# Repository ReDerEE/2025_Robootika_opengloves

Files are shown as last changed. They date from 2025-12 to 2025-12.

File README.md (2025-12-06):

# Robootika iseseisev arendusprojekt

See repositoorium on mõeldud IFI6203.DT kursuse "Robootika" üliõpilastele.  
Iga meeskond **forkib** selle repo ja dokumenteerib siin oma seadme/projekti:
- *mis probleemi lahendate ja miks see seade kasulik on;*
- *millest seade koosneb (riistvara, kood, 3D prinditud detailid jne);*
- *kuidas seade töötab;*
- *kuidas seda uuesti ehitada.*

## Kuidas seda repo't kasutada

1. Vajuta ülal paremas nurgas **Fork**.
2. Muuda `docs/PROJEKTIDOKUMENTATSIOON.md` enda projekti järgi.
3. Pane kogu kood kataloogi `src/`.
4. Pane skeemid ja riistvara info kataloogi `hardware/`.
5. Lisa pildid / videod kataloogi `media/`.
6. Commiti regulaarselt (isegi pooleliolevad sammud on okei – oluline on arengulugu).

## Projekti minimaalne sisu hindamiseks

- Täidetud dokumentatsioon failis `docs/PROJEKTIDOKUMENTATSIOON.md`
- Töötav kood failis/failides `src/`
- Ühendusskeem (foto / joonis / Fritzing eksport `hardware/wiring-diagram.png`)
- Komponentide loetelu koos linkidega `hardware/komponentide-loetelu.md`

## Meeskond

- Õppeaine: IFI6203.DT Robootika  
- Autor(id): Carl-Eric Sepp, Henri Rihard Pallas
- Aasta / semester: 2025 Sügis

> NB! Ärge kustutage osi, mis on nõutud, küll aga võite lisada lisafaile (katsetused, logid, alternatiivsed skeemid jne).

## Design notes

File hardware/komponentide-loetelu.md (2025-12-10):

# Komponentide loetelu

## Põhikomponendid
**Komponendid ühe (1) kinda kohta, mõlema käe jaoks kahekordistada.**
- _(1x) ESP32-WROOM-32U WROVER_
- _(1x) Xiaomi Redmi Power Bank (20000mAh)_
- _(5x) MG90S Micro Servo Motor (180)_
- _(1x) Joystick, Joystick for Arduino Dual-axis_
- _(5x) Rotary Potentiometer (6mm, 3 pin, 10K ohm)
- _(Optional) Momentary Push Button Switch_  
- _(5x) Vedru (Vaadake lingid/allikad alla)_
- _(5x) Nööri (Vaadake lingid/allikad alla)_
- _Kaablid_
- _Kaablite otsad_

3D Prinditud:
- _End caps (hardware/3D/EndCaps.stl)_
- _Guide Nodes (hardware/3D/GuideNode.STL)_
- _Guide Rings (hardware/3D/guideRings.stl)_
- _Haptic Spool (hardware/3D/HapticSpool.stl)_
- _Left hand mount (hardware/3D/LeftHandMount.STL)_
- _Potentiometer holder (hardware/3D/PotHolder.STL)_
- _Quest2 holder (hardware/3D/Quest2Holder.stl)
- _Right hand mount (hardware/3D/RightHandMount.STL)_
- _Spool cover (hardware/3D/Spoolcover.stl)_
- _Tensioner (hardware/3D/Tensioner.stl)_

## Lingid / allikad
- ESP32-WROOM-32U WROVER – [Aliexpress](https://www.aliexpress.com/item/1005008209898668.html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)
- Xiaomi Redmi Power Bank 20000mAh – [Arvutitark](https://arvutitark.ee/en/smart-devices/smart-device-accessories/akupangad/xiaomi-redmi-fast-charge-power-bank-20000-mah-black-18-w-1017875)
- MG90S Micro Servo Motor – [Aliexpress](https://www.aliexpress.com/item/1005005672961991.html?spm=a2g0o.order_list.order_list_main.20.30fa1802Zp5XaK)
- Joystick for Arduino Dual-axis - [Aliexpress](https://www.aliexpress.com/item/1005007915984781.html?spm=a2g0o.order_list.order_list_main.30.30fa1802Zp5XaK)
- Nupud - [Aliexpress_ET](https://www.aliexpress.com/item/4001081730289.html?spm=a2g0o.order_list.order_list_main.40.30fa1802Zp5XaK) [Aliexpress_EN](https://www.aliexpress.us/item/2255800895415537.html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)
- Potentsiomeetrid - [Aliexpress](https://www.aliexpress.com/item/33011428749.html?spm=a2g0o.order_list.order_list_main.25.30fa1802Zp5XaK)
- Kaablid - [Aliexpress](https://www.aliexpress.com/item/1005007156114505.html?spm=a2g0o.order_list.order_list_main.50.30fa1802Zp5XaK)
- Kaablite otsad [Aliexpress](https://www.aliexpress.com/item/1005007425641197.html?spm=a2g0o.order_list.order_list_main.15.30fa1802Zp5XaK)
- Nöörid ja vedrud saadud antud toote lahti võtmisel [Aliexpress](https://www.aliexpress.us/item/3256803821144861.html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)

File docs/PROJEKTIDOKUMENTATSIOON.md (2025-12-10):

# Projekti dokumentatsioon

## 1. Projekti eesmärk ja seadme lühikirjeldus
**Mis asi see on, mida ja miks me teeme? Millist praktilist probleemi see lahendab?**

- Meie projekti eesmärk on luua haptilised kindad, mida saab kasutada virtuaal reaalsues (VR), virutaalsete objektide tunnetamiseks.
- Seade annab võimaluse oma enda kätega tunnetada virtuaalseid objekte, aitab kaasa virtuaal reaalsuse immersiooniga.
- Peamised komponendid: ESP32 mikrokontroller, akupangad, servomootorid, joystick, potentsiomeetrid, nupp, vedrud, nöörid, 3d prinditud osad kinnitamiseks ja kandmiseks. 

---

## 2. Sisendite loetelu
**Millised on süsteemi poolt loetavad / mõõdetavad sisendid? Millega neid mõõdetakse / tuvastatakse?**

- Potentsiomeetrid:
  - Väikesõrme painutus -> analoogpinge loetakse ESP32 pinilt **PIN_PINKY (36)**
  - Nimetissõrme painutus -> analoogpinge ESP32 pinilt **PIN_RING (39)**
  - Keskmise sõrme painutus -> analoogpinge ESP32 pinilt **PIN_MIDDLE (34)**
  - Nimetissõrme painutus -> analoogpinge ESP32 pinilt **PIN_INDEX (35)**
  - Pöidla painutus -> analoogpinge ESP32 pinilt **PIN_THUMB (32)**

- Joystick
  - Joystick X-telg -> analoogpinge ESP32 pinilt **PIN_JOY_X (12)**
  - Joystick Y-telg -> analoogpinge ESP32 pinilt **PIN_JOY_Y (14)**
  - Joystick vajutusnupp -> digitaalne sisend ESP32 pinilt **PIN_JOY_BTN (26)**

- Bluetooth sisend -> Saab kätte mootorite kontrollimiseks vajaliku informatsiooni.
---

## 3. Väljundite loetelu
**Mida süsteem teeb / muudab? Millega väljund realiseeritakse?**

- Sõrmede jõutagasiside (force feedback):
  Osutavad vastupanu, kui kasutaja puudutab midagi virtuaal reaalsuses.
  - Väikesõrme servo/mootor -> **PIN_PINKY_MOTOR (5)**
  - Nimetissõrme servo/mootor -> **PIN_RING_MOTOR (18)**
  - Keskmise servo/mootor -> **PIN_MIDDLE_MOTOR (19)**
  - Nimetissõrme servo/mootor -> **PIN_INDEX_MOTOR (16)**
  - Pöidla servo/mootor -> **PIN_THUMB_MOTOR (17)**

- Debug LED -> **LED (PIN 2)**

- Bluetooth väljund -> Saadab sõrmede asendid, Žestide olekud, Joysticki asendi.

---

## 4. Nõuded loodavale seadmele
**Mis peab toimuma, kui kasutaja teeb mingi toimingu? Kirjelda käitumisloogika.**

- Kui näpp liigutatakse, siis see saadab näppude painduvuse edasi, siis driver tõlgendab seda Valve Knuckles grip väärtuseks.
- Kui kasutaja liigutab käe interactible objekti lähedusse, siis see paneb servod käima, et kasutaja ei saaks objekti mõistes näppe sellest läbi pista(force feedback osa)
- Kui kasutaja liigutab joystick'i, siis see saadetakse driver'ile ja see tõlgib seda reaalsel kasutatavaks vr joystick'i liigutuseks 

---

## 5. Süsteemi füüsiliste komponentide loetelu
**Millest seade koosneb? Lisa lingid või täpsed nimed, et keegi teine saaks sama asja uuesti osta / teha.**

Tabelina või punktidena. Nt:

- _(1x) ESP32-WROOM-32U WROVER_ [Aliexpress](https://www.aliexpress.com/item/1005008209898668.html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)
- _(2x) Xiaomi Redmi Power Bank (20000mAh)_ [Arvutitark](https://arvutitark.ee/en/smart-devices/smart-device-accessories/akupangad/xiaomi-redmi-fast-charge-power-bank-20000-mah-black-18-w-1017875)
- _(5x) MG90S Micro Servo Motor (180)_ [Aliexpress](https://www.aliexpress.com/item/1005005672961991.html?spm=a2g0o.order_list.order_list_main.20.30fa1802Zp5XaK)
- _(1x) Joystick, Joystick for Arduino Dual-axis_ [Aliexpress](https://www.aliexpress.com/item/1005007915984781.html?spm=a2g0o.order_list.order_list_main.30.30fa1802Zp5XaK)
- _(5x) Rotary Potentiometer (6mm, 3 pin, 10K ohm) [Aliexpress](https://www.aliexpress.com/item/33011428749.html?spm=a2g0o.order_list.order_list_main.25.30fa1802Zp5XaK)
- _(Optional) Momentary Push Button Switch_  [Aliexpress_ET](https://www.aliexpress.com/item/4001081730289.html?spm=a2g0o.order_list.order_list_main.40.30fa1802Zp5XaK) [Aliexpress_EN](https://www.aliexpress.us/item/2255800895415537.html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)
- _(5x) Vedru ja (5x) Nööri (Saadud lingitud toote lahti lammutamisel.)_ [Aliexpress](https://www.aliexpress.us/item/3256803821144861.html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)
- _Kaablid_ [Aliexpress](https://www.aliexpress.com/item/1005007156114505.html?spm=a2g0o.order_list.order_list_main.50.30fa1802Zp5XaK)
- _Kaablite otsad_ [Aliexpress](https://www.aliexpress.com/item/1005007425641197.html?spm=a2g0o.order_list.order_list_main.15.30fa1802Zp5XaK)
- _3D prinditud osad_ (hardware/3D kaustas)

---

## 6. Ühendusskeem
**Kuidas kõik osad on omavahel ühendatud?**
[hardware/wiring-diagram.png]

- Väikesõrme Potentsiomeeteri asend -> **PIN_PINKY (36)**
- Nimetissõrme Potentsiomeeteri asend -> **PIN_RING (39)**
- Keskmise sõrme Potentsiomeeteri asend -> **PIN_MIDDLE (34)**
- Nimetissõrme Potentsiomeeteri asend -> **PIN_INDEX (35)**
- Pöidla Potentsiomeeteri asend -> **PIN_THUMB (32)**

- Joystick X-telg asend -> **PIN_JOY_X (12)**
- Joystick Y-telg asend -> **PIN_JOY_Y (14)**
- Joystick nupu vajutus -> **PIN_JOY_BTN (26)**

- Väikesõrme servo/mootor -> **PIN_PINKY_MOTOR (5)**
- Nimetissõrme servo/mootor -> **PIN_RING_MOTOR (18)**
- Keskmise servo/mootor -> **PIN_MIDDLE_MOTOR (19)**
- Nimetissõrme servo/mootor -> **PIN_INDEX_MOTOR (16)**
- Pöidla servo/mootor -> **PIN_THUMB_MOTOR (17)**

- Väikesõrme Potentsiomeeter ground -> **PIN(GROUND)**
- Nimetissõrme Potentsiomeeter ground -> **PIN(GROUND)**
- Keskmise sõrme Potentsiomeeter ground -> **PIN(GROUND)**
- Nimetissõrme Potentsiomeeter ground -> **PIN(GROUND)**
- Pöidla Potentsiomeeter ground -> **PIN(GROUND)**
- Väikesõrme servo/mootor ground -> **PIN(GROUND)**
- Nimetissõrme servo/mootor ground -> **PIN(GROUND)**
- Keskmise servo/mootor ground -> **PIN(GROUND)**
- Nimetissõrme servo/mootor ground -> **PIN(GROUND)**
- Pöidla servo/mootor ground -> **PIN(GROUND)**
- Joystick ground -> **PIN(GROUND)**
- Nupp ground -> **PIN(GROUND)**
- Vooluallika ground -> **PIN(GROUND)**

- Vooluallikas 1 -> **PIN(5V/Voltage In)** või **USB-C Input**
- Vooluallikas 2 -> Kõik servomootorid

- **PIN(3.3V)** -> Väikesõrme Potentsiomeeteri vool
- **PIN(3.3V)** -> Nimetissõrme Potentsiomeeteri vool
- **PIN(3.3V)** -> Keskmise sõrme Potentsiomeeteri vool
- **PIN(3.3V)** -> Nimetissõrme Potentsiomeeteri vool
- **PIN(3.3V)** -> Pöidla Potentsiomeeteri vool
- **PIN(3.3V)** -> Joystick vool

---

## 7. Süsteemi juhtiv kood (või pseudokood)
**Kirjelda programmi loogikat nii, et seda on võimalik aru saada ka hiljem.**  
[src/lucidgloves-main]  

Kontroller loeb potentsiomeetrite ja joystick-i olekut ning saab läbi bluetoothi informatsiooni driverilt.
Kontroller käivitab servod, kui kasutaja puudutab virtuaalses reaalsuses objekti.
Servod hoiavad käe ja sõrmed paigal, ei lase neil virtuaalse objekti sisse vajuda.
Kontroller saadab driverile potentsiomeetrite ja joystick-i seisundid (nupud ka, kui on).

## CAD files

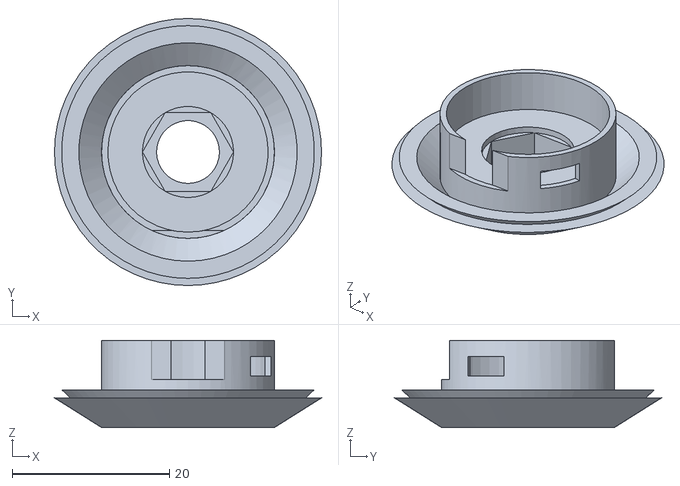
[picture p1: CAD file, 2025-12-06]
hardware/3D/Tensioner.stl
34.0 x 34.0 x 11.1

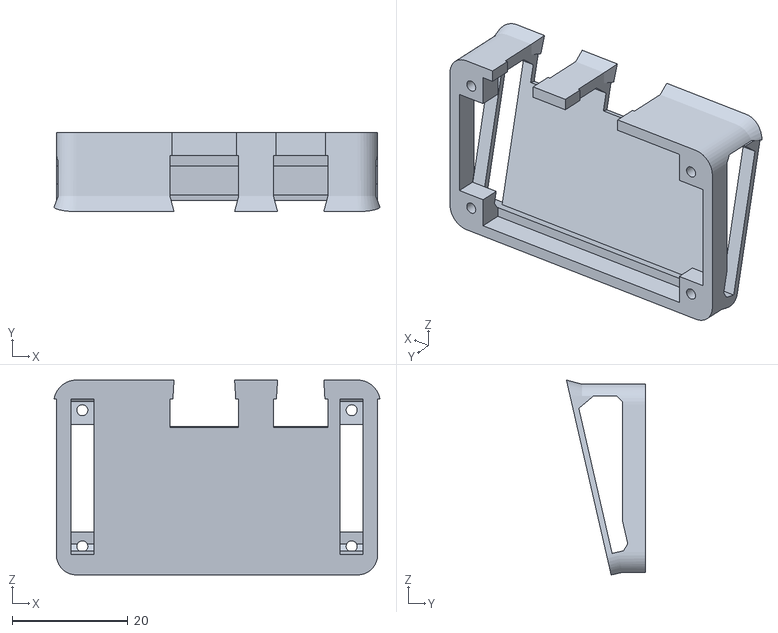
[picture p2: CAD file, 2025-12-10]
src/lucidgloves-main/lucidgloves-main/hardware/MicrocontrollerMounts/ESP32_Wroom_Holder_Desoldered_JST.STL
56.3 x 13.7 x 33.7

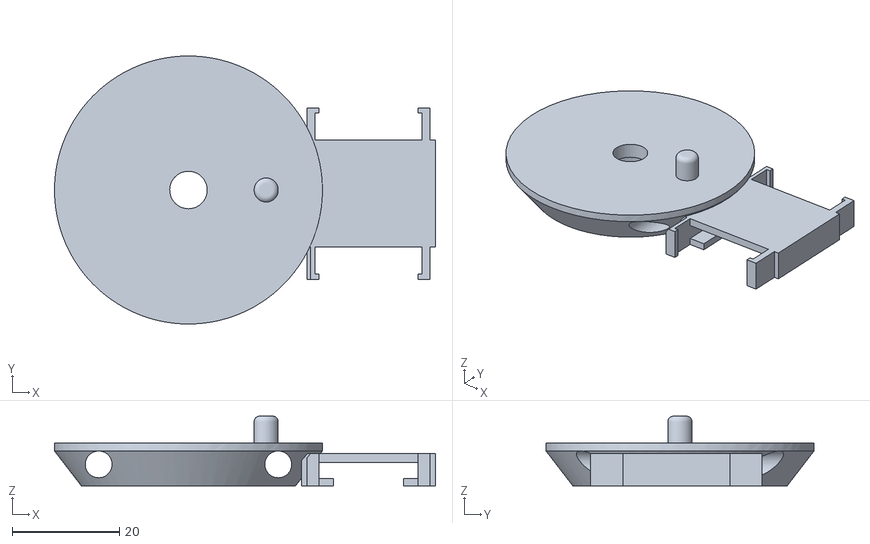
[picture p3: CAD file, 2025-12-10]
src/lucidgloves-main/lucidgloves-main/hardware/Prototype4.1/Vive3.0_MountSlider_v1.2.STL
71.1 x 50.0 x 13.0

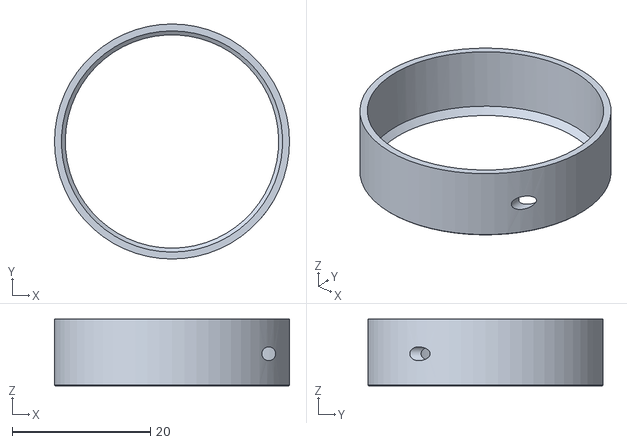
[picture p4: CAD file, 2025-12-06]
hardware/3D/Spoolcover.stl
34.0 x 34.0 x 9.63

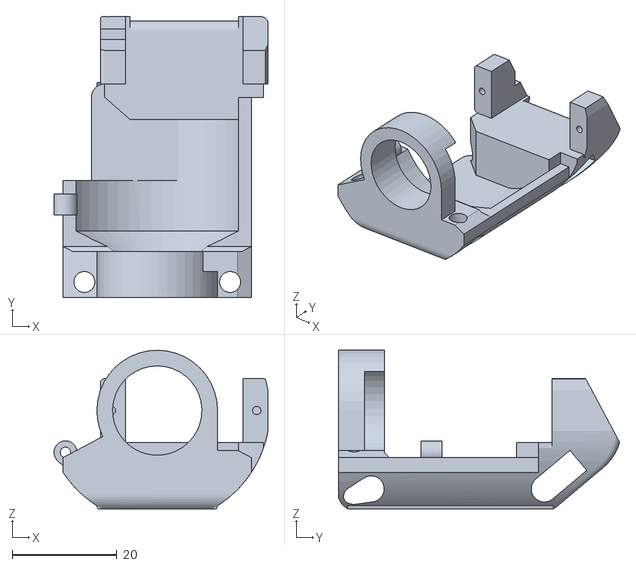
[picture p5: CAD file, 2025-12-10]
src/lucidgloves-main/lucidgloves-main/hardware/Prototype4.1/WLPotElasticHolder_Proto4.1.STL
41.0 x 53.9 x 30.3

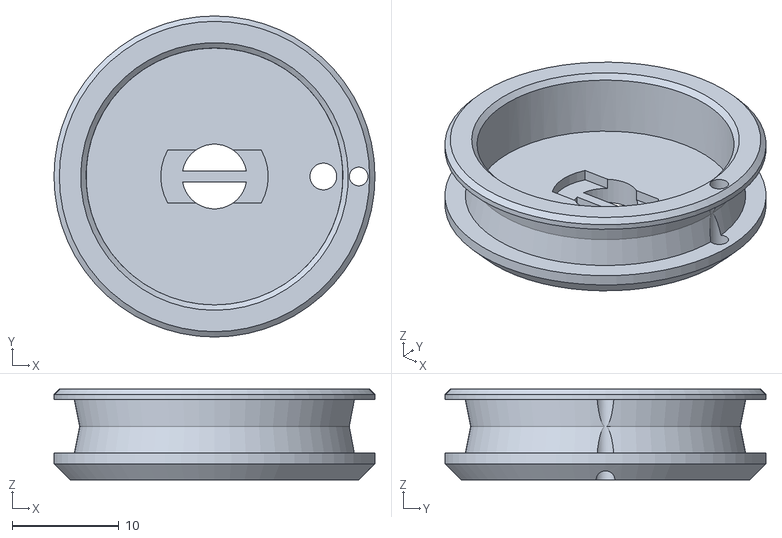
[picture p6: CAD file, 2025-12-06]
hardware/3D/HapticSpool.stl
30.0 x 30.0 x 8.50

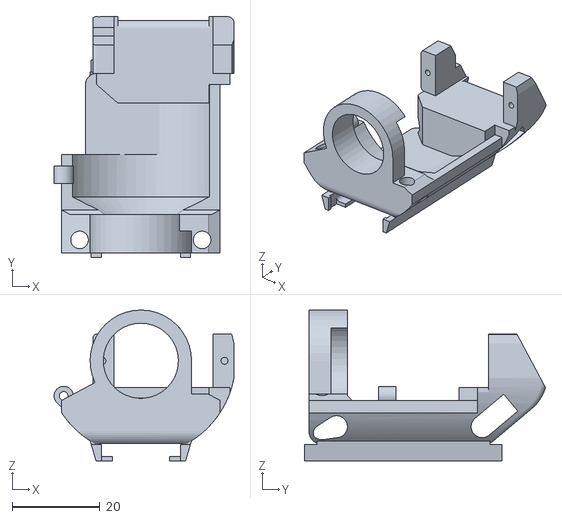
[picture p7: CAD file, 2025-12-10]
src/lucidgloves-main/lucidgloves-main/hardware/Prototype4.1/WLPotSlideHolder_Proto4.1.STL
41.0 x 54.9 x 34.3

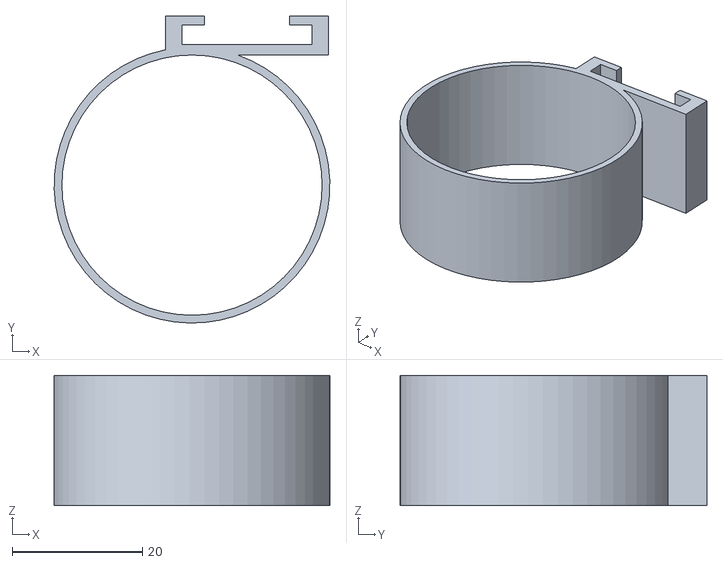
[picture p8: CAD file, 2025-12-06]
hardware/3D/Quest2Holder.stl
42.4 x 47.2 x 20.0

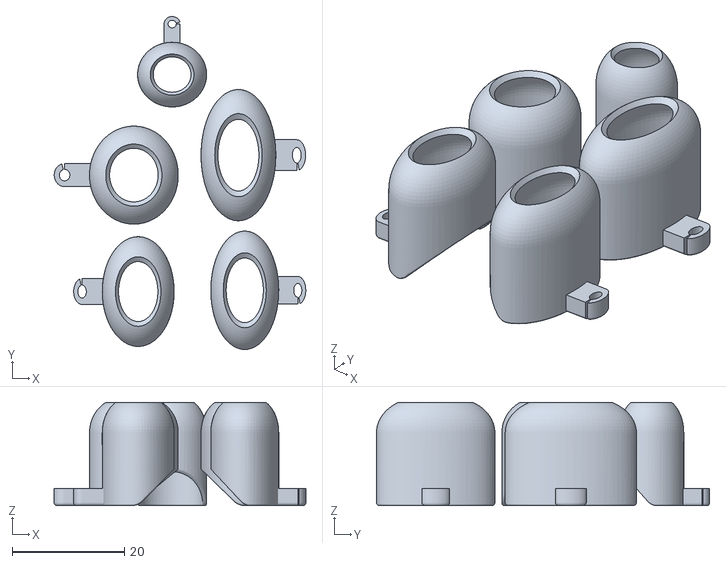
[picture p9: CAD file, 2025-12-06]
hardware/3D/EndCaps.stl
44.9 x 59.4 x 18.4

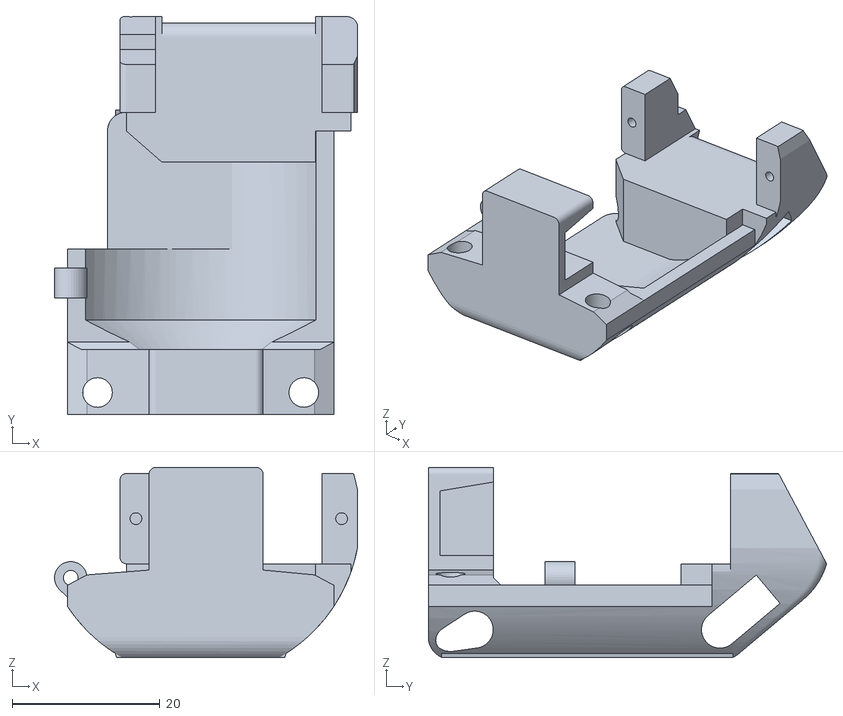
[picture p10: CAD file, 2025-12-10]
src/lucidgloves-main/lucidgloves-main/hardware/Prototype4.1/GreenPotElasticHolder_Proto4.1.STL
41.0 x 53.9 x 25.8

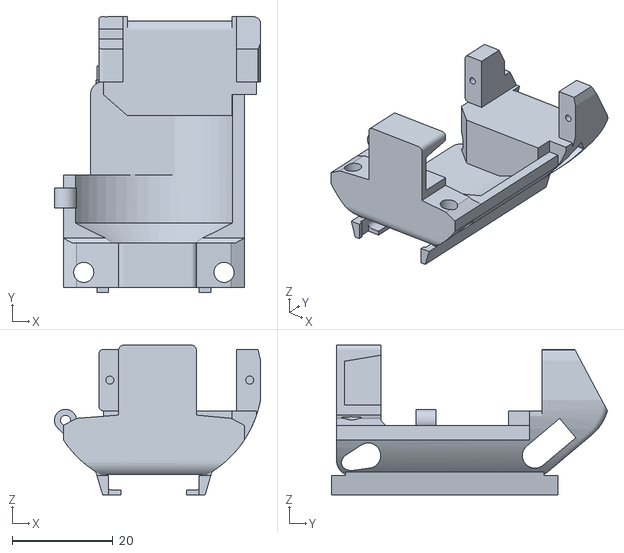
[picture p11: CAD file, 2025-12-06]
src/lucidgloves-main/lucidgloves-main/hardware/Prototype4.1/GreenPotSildeHolder_Proto4.1.STL
41.0 x 54.9 x 29.8

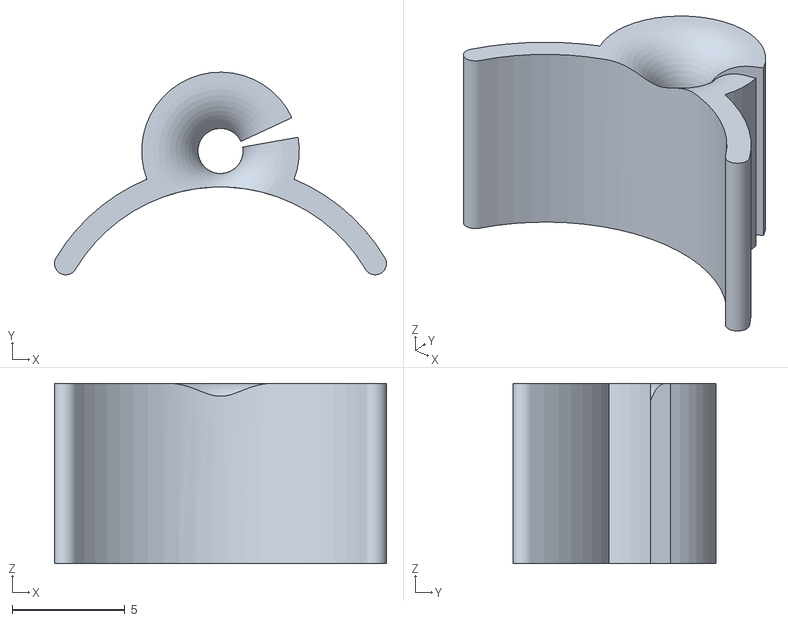
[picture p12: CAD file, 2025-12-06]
src/lucidgloves-main/lucidgloves-main/hardware/Prototype4.1/GuideNode_upgraded.STL
14.7 x 9.00 x 8.00

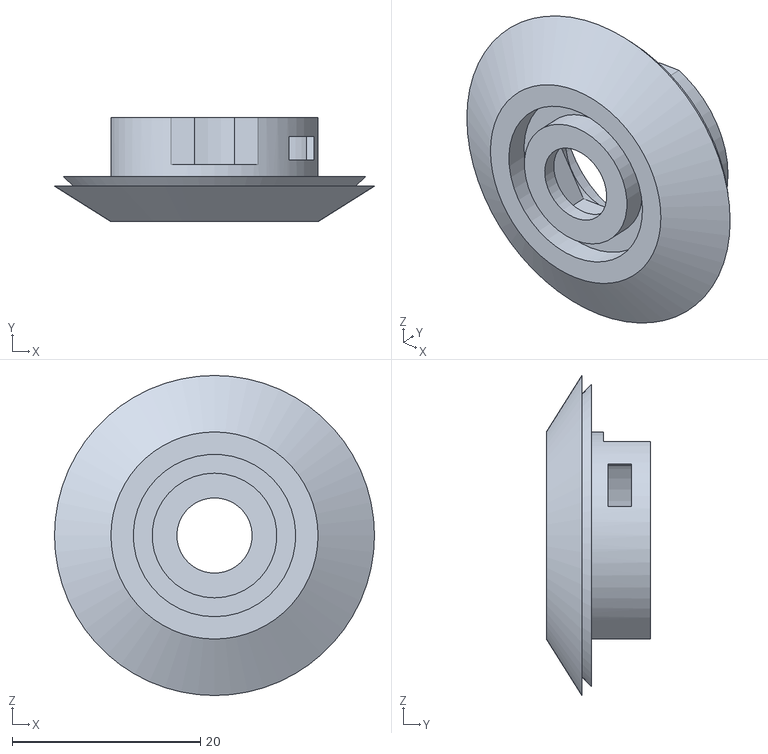
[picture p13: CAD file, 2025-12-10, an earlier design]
src/lucidgloves-main/lucidgloves-main/hardware/Prototype3.1/Prot3.1_Tensioner.STL
34.0 x 11.1 x 34.0

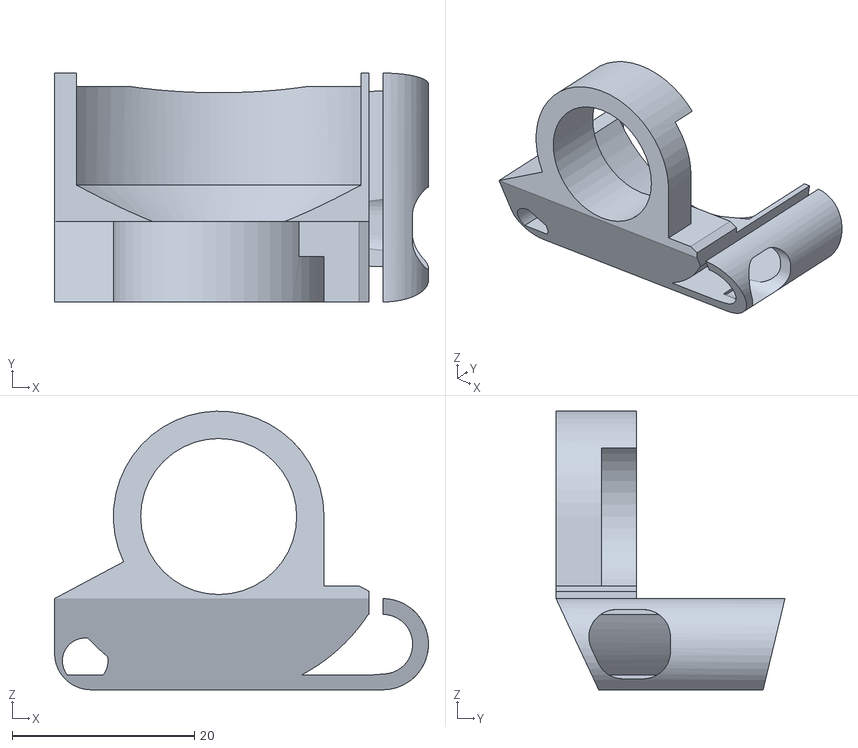
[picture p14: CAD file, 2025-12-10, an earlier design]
src/lucidgloves-main/lucidgloves-main/hardware/Prototype3/Prot3_Holder.STL
41.0 x 25.1 x 30.5

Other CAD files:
src/lucidgloves-main/lucidgloves-main/hardware/Prototype4.1/HapticSpool_Proto4.1.STL
src/lucidgloves-main/lucidgloves-main/hardware/Prototype3.1/Prot3.1_GuideNode.STL
src/lucidgloves-main/lucidgloves-main/hardware/Prototype3/Prot3_EndCap.STL
src/lucidgloves-main/lucidgloves-main/hardware/Prototype3.1/Prot3.1R2_EasySpool.STL
src/lucidgloves-main/lucidgloves-main/hardware/Prototype3.1/Prot3.1R2_SpoolCover.STL
src/lucidgloves-main/lucidgloves-main/hardware/Prototype3.1/Prot3.1R2_SpoolCover_Taller.STL
src/lucidgloves-main/lucidgloves-main/hardware/Prototype3.1/Prot3.1_Holder.stl
src/lucidgloves-main/lucidgloves-main/hardware/Prototype3.1/Prot3.1_Wirecover_PublicBeta.STL
src/lucidgloves-main/lucidgloves-main/hardware/Prototype3.1/Prot3_EndCap.STL
src/lucidgloves-main/lucidgloves-main/hardware/Prototype3/Prot3_Cover.STL
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

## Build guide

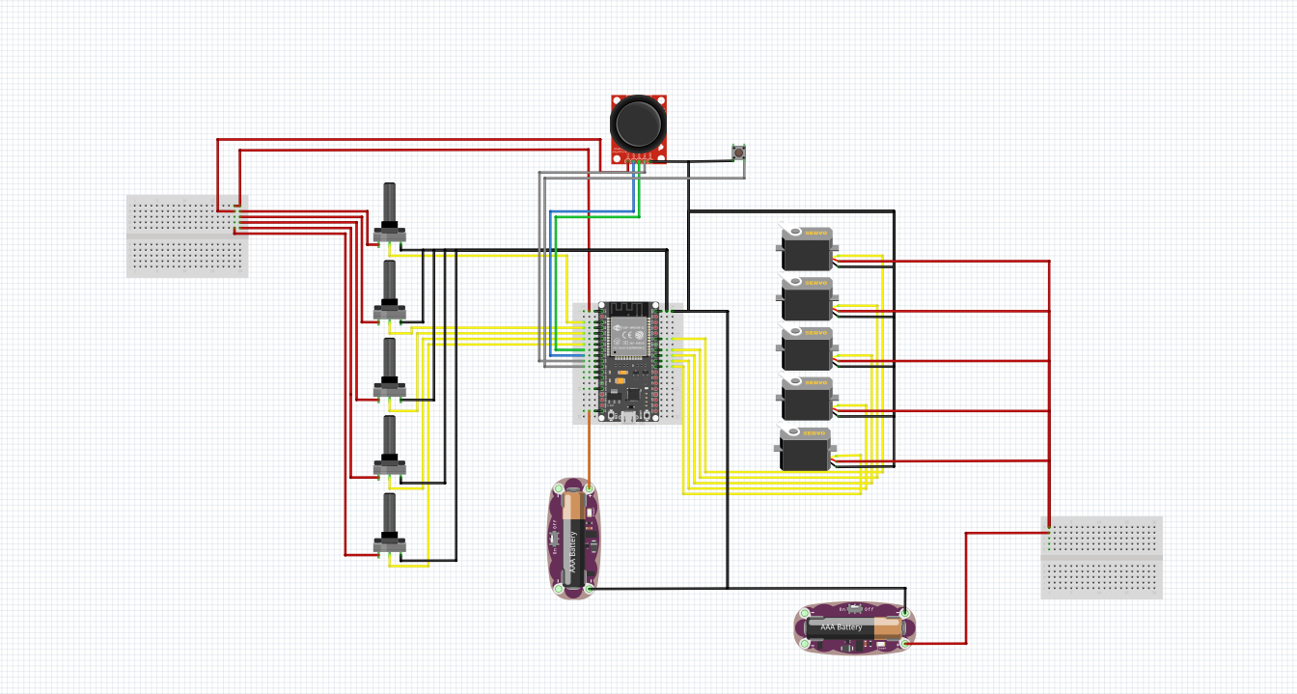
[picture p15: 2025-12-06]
hardware/wiring-diagram.png

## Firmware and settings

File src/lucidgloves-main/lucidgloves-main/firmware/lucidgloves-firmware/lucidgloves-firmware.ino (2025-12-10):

/*
 * LucidGloves Firmware Version 4
 * Author: Lucas_VRTech - LucidVR
 * lucidvrtech.com
 */

#include "AdvancedConfig.h"

//This is the configuration file, main structure in _main.ino
//CONFIGURATION SETTINGS:
#define COMMUNICATION COMM_BTSERIAL //Which communication protocol to use
//serial over USB
  #define SERIAL_BAUD_RATE 115200
  
//serial over Bluetooth
  #define BTSERIAL_DEVICE_NAME "rightie-cutie2"

//ANALOG INPUT CONFIG
#define FLIP_POTS false  //Flip values from potentiometers (for fingers!) if they are backwards

//Gesture enables, make false to use button override
#define TRIGGER_GESTURE true
#define GRAB_GESTURE    true
#define PINCH_GESTURE   true


//BUTTON INVERT
//If a button registers as pressed when not and vice versa (eg. using normally-closed switches),
//you can invert their behaviour here by setting their line to true.
//If unsure, set to false
#define INVERT_A false
#define INVERT_B false
#define INVERT_JOY false
#define INVERT_MENU false
#define INVERT_CALIB false 
//These only apply with gesture button override:
#define INVERT_TRIGGER false
#define INVERT_GRAB false
#define INVERT_PINCH false


//joystick configuration
#define JOYSTICK_BLANK false //make true if not using the joystick
#define JOY_FLIP_X false
#define JOY_FLIP_Y false
#define JOYSTICK_DEADZONE 10 //deadzone in the joystick to prevent drift (in percent)

#define NO_THUMB false //If for some reason you don't want to track the thumb

#define USING_CALIB_PIN true //When PIN_CALIB is shorted (or it's button pushed) it will reset calibration if this is on.

#define USING_FORCE_FEEDBACK true //Force feedback haptics allow you to feel the solid objects you hold
#define SERVO_SCALING false //dynamic scaling of servo motors

#if defined(ESP32)
  //(This configuration is for ESP32 DOIT V1 so make sure to change if you're on another board)
  #define PIN_PINKY     36
  #define PIN_RING      39
  #define PIN_MIDDLE    34
  #define PIN_INDEX     35
  #define PIN_THUMB     32
  #define PIN_JOY_X     12
  #define PIN_JOY_Y     14
  #define PIN_JOY_BTN   26
  #define PIN_A_BTN     27 
  #define PIN_B_BTN     14
  #define PIN_TRIG_BTN  12 //unused if gesture set
  #define PIN_GRAB_BTN  13 //unused if gesture set
  #define PIN_PNCH_BTN  23 //unused if gesture set
  #define PIN_CALIB     0 //button for recalibration (You can set this to GPIO0 to use the BOOT button, but only when using Bluetooth.)
  #define DEBUG_LED 2
  #define PIN_PINKY_MOTOR     16 //used for force feedback
  #define PIN_RING_MOTOR      17 //^
  #define PIN_MIDDLE_MOTOR    5 //^
  #define PIN_INDEX_MOTOR     18 //^
  #define PIN_THUMB_MOTOR     19 //^
  #define PIN_MENU_BTN        27
  
//PINS CONFIGURATION 
#elif defined(__AVR__)
  //(This configuration is for Arduino Nano so make sure to change if you're on another board)
  #define PIN_PINKY     A0
  #define PIN_RING      A1
  #define PIN_MIDDLE    A2
  #define PIN_INDEX     A3
  #define PIN_THUMB     A4
  #define PIN_JOY_X     A6
  #define PIN_JOY_Y     A7
  #define PIN_JOY_BTN   7 
  #define PIN_A_BTN     8 
  #define PIN_B_BTN     9
  #define PIN_TRIG_BTN  10 //unused if gesture set
  #define PIN_GRAB_BTN  11 //unused if gesture set
  #define PIN_PNCH_BTN  12 //unused if gesture set
  #define PIN_CALIB     13 //button for recalibration
  #define DEBUG_LED     LED_BUILTIN
  #define PIN_PINKY_MOTOR     2 //used for force feedback
  #define PIN_RING_MOTOR      3 //^
  #define PIN_MIDDLE_MOTOR    4 //^
  #define PIN_INDEX_MOTOR     5 //^
  #define PIN_THUMB_MOTOR     6 //^
  #define PIN_MENU_BTN        8
#endif

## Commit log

2025-12-06 Added components and files to hardware folder
    [EndCaps.stl, GuideNode.STL, HapticSpool.stl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]
2025-12-06 Separated 3d files into separate folder
    [EndCaps.stl, GuideNode.STL, HapticSpool.stl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]
2025-12-10 added requirements for the device
2025-12-10 added code and made adjustments
    [ESP32_Wroom_Holder_Desoldered_JST.STL, GreenPotElasticHolder.stl, GreenPotElasticHolder_Proto4.1.STL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]
